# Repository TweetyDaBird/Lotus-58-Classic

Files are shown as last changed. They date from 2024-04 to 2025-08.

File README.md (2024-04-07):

### Notice! Files in the development branches are NOT intended for public use in production of PCB's, may or may not be tested and may change or be removed without notice! 
Please use the Gerber files for producing PCB's, found under the header 'Releases' instead. Also please note the difference between a 'Pre-release' (partially/fully untested, basically what I order a prototype PCB from to test) and a full actual 'Release' which is fully tested, built and ready to be used to produce PCB's.

That said, if you want to tweak/change or make something new based on my project, I can point you to a suitable starting point in the raw files. Talk to me, and I'm happy to help.
# Lotus 58 Glow

Starting with simple tweaks to the Lily58 Glow before ordering a set of PCB's it quickly spiraled out of control, and I ended up with what wasn't quite a Lily58 anymore, and although very similar in layout, it is no longer compatible with plate and case design. 

Because of this, it was renamed Lotus58, referencing another flower much like the lily in the name Lily58.

Lotus 58 Glow
(photo from reddit by u/bduzik)

## General Specifications

- Layout very similar to the original Lily58 family
- Per key RGB and RGB underglow
- Kaihl Hot-swap sockets for MX compatible switches
- Can be used as a standalone Gamepad for either hand
- Optional 0.91" OLED Screens and rotary encoders (one each per side)
- All components through-hole and easily soldered for beginners (SMD option for diodes)
- Designed with a sandwich-style plate/case as part of the design

## Layout variations

- Optional plate layout with OLED screen (Encoder can be placed on upper thumb key position)
- Optional plate layout with rotary encoder (Removes OLED screen for that side)  
- Optional plate layout with no hole for OLED or upper encoder (Encoder can be placed on upper thumb key position)

Layout variations Layout Variations

## Things to note when ordering PCB's
### Finding the Gerber files
If you are not aiming at modifying things, don't look for the gerber files in the folders, pretty please!</BR>
And please don't open yet another issue about it! </BR>
The gerber files are where they belong, zipped up in releases, look under that header for the version you want.

### Tips & Tricks
- Most PCB manufacturers have a MOQ of 5 PCB's, meaning you end up with 2½ keyboards when finished.
- The recommended PCB thickness is 1.6 mm, both for the main PCB and plates to allow the keyswitches to grip the plate and lock in place securely.

If ordering from [JLCPCB](https://www.jlcpcb.com) the plate Gerber files include a reference putting the added serial etc on a breakaway part for a clean look with minimal cost, if using another manufacturer it's possible they have additional fee's for removing the extra text, or you should consider plotting the Gerber files yourself with the correct reference for your manufacturer. Otherwise use the standard settings from JLPCB.

## Buy a kit!
I sell complete kits, making it easy to build your keyboard, and it also supports prototypes for new wacky ones. 



## Discord for build help and discussions!

<a href="https://discord.gg/G6QzcJQUnm">Discuss on Discord</a>

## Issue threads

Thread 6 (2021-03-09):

Latest version

fi0, 2021-03-09:
Which version should I build?

azzamsa, 2021-03-10:
Yes, According to the timestamp `5 days ago`. `v1.06` is the latest release.

TweetyDaBird, 2021-03-12:
The plates and PCB's are in separate packages, since you cannot order them as one item from a manufacturer (one order, but multiple items). As such, they have separate version numbers.

So for a complete keyboard you'd need the v1.1 PCB's and bottom plates plus whichever top plates you pick to go along with them, from either package of plates.

fi0, 2021-03-12:
Thank you! I was confused with PCB versions and plate versions. I should have looked into https://github.com/TweetyDaBird/Lotus58/releases instead of the tags.

Closed 2021-03-12.

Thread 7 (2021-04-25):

Lily58 plates

fabioluciano, 2021-04-25:
Can I use my lily58 pro plates with lotus? Or there is some differences that make this impossible?

TweetyDaBird, 2021-05-17:
No, you cannot, as the outline and hole pattern aren't the same

Closed 2021-05-17.

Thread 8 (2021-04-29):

Resistor

fi0, 2021-04-29:
Is the 2W 4.7k resistor the right one?
or can I get smaller ones?

TweetyDaBird, 2021-05-17:
That link has been corrected, 2W will be far to bulky to fit properly.

Closed 2021-05-17.

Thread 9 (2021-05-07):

Reset switch BOM

fi0, 2021-05-07:
Which reset switch should I buy?

resoursa, 2021-05-07:
No need switch, just short [2nd and 3rd ](https://cvws.icloud-content.com/B/AVL4BtLX9XralGjamo27pjZ8xJKQAZJxWLW_ZPGzBZRlLMc_Q9SvoXsU/Screenshot+2021-05-07+at+09.17.07.png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)contact on arduino.

Closed 2021-05-19.

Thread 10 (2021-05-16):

LED pinouts not the same for SK6812MINI and SK6812MINI-E

mwmccarthy, 2021-05-16:
The pinout for the SK6812-MINI matches the orientation of the PCB for soldering from the bottom with the lens facing away from you as you solder:

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

However, the SK6812MINI-E would need to be soldered from the top of the PCB with the lens facing up in order for the VDD and GND pins to line up, but then DIN and DOUT are swapped:

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

TweetyDaBird, 2021-05-17:
Well, that's altogether stupid that I hadn't verified that part. I have only built with wigless, and figured (without checking) that tehy had the same pinout.

Removing them from parts list.

phil123456, 2024-05-06:
there are so many pinouts of the mini version, which one is correct ? does this depend of the manufacturer or are they all the same ?

TweetyDaBird, 2024-05-06:
> there are so many pinouts of the mini version, which one is correct ? does this depend of the manufacturer or are they all the same ?

Each standardized model has a pin out. That's the same from whatever seller, as they all come form the same producer. But no, mini and mini-e are not the same, and never will be.

Closed 2021-05-17.

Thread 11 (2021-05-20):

Pro Micro RP2040

dunkfordyce, 2021-05-20:
https://www.sparkfun.com/products/17717

Apart from the code changes, would this theoretically work as a drop in replacement?
They are half the price of a standard Pro Micro. I have already had luck using CircuitPython on a plain RPi Pico to create a mech keyboard.

TweetyDaBird, 2021-05-20:
Well, since it’s pin compatible with ProMicro I see no reason why not.

dunkfordyce, 2021-05-22:
Thanks!

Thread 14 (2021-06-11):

Incorrect TH diode identifier

AbhilashGayen, 2021-06-11:
In readme, for diodes,
- update 1N4841(TH) to 1N4148(TH)

TweetyDaBird, 2021-06-16:
Fixed, thank you!

Closed 2021-06-16.

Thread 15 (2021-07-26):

Symmetrical design in Gerbers?

ruehri, 2021-07-26:
Sorry if this is a stupid question (this is the first keyboard that I plan to build): Are all the Gerber files (especially the PCB) symmetrical in a sense that we can use them for both right and left hand? So if I made an order from JLCPBC for 5x the PCB, I could build 2.5 full keyboards - no need for any mirroring of the design, correct?

TweetyDaBird, 2021-07-27:
Exactly correct, the PCB's are symmetrical. You will however 'need' the plates as well to make a complete keyboard. Either as PCB material, or laser cut etc.

ruehri, 2021-08-12:
Thanks! Ordered them (along with all the other stuff from Ali) and look forward to building it

Closed 2021-08-12.

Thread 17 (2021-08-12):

Where is the breakaway part for when you order from JLCPCB?

SuperNici, 2021-08-12:
You mentioned [here](https://github.com/TweetyDaBird/Lotus58#things-to-note-when-ordering-pcbs) that you have added a breakaway part on the PCB Gerber files.

> If ordering from JLPCB the plate Gerber files include a reference putting the added serial etc. on a breakaway part for a clean look with minimal cost, if using another manufacturer it's possible they have additional fee's for removing the extra text, or you should consider plotting the Gerber files yourself with the correct reference for your manufacturer.

I've been looking for it for a while and couldn't find it.

Hybrid-Force, 2021-08-16:
Hey there, I think the breakaway parts were removed in commit 5263f9b0050a36a8181bea90f3474fcbf5af5144. The reference text for serial number was originally on the breakaway part of the upper thumb key.

TweetyDaBird, 2021-08-23:
This depends on if you pick the plates with breakaway parts in the switch holes or not. The plates are available both ways to allow it to work with all PCB manufacturers.

Usually the text is small an unobtrusive enough that it’s hidden under the keycaps, but if you choose to order the PCB’s yourself, it’s worth to check and re-render as needed. Or pay the usually minimal fee to have the text removed. My comment was more aimed at making you aware of this, than an exact roadmap to how to order.

BTW, if you prefer to not bother with ordering yourself, I’m selling PCB kits on tindie at what I think are pretty reasonable prices.

SuperNici, 2021-08-23:
Appreciate the comments @Hybrid-Force and @TweetyDaBird.

I feel like playing the small extra fee on jlcpcb will be worth it.

>BTW, if you prefer to not bother with ordering yourself, I’m selling PCB kits on tindie at what I think are pretty reasonable prices.

You should absolutely put that in the read me! I would have never known! Though for myself i will (soon) order the parts myself because I'll be adding some small stuff to the pcb.

And to support these kinds of open source projects ill also make sure to donate a small amount to you three main contributors :)

Closed 2021-08-23.

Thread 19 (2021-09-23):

Various question

dmikhalsky, 2021-09-23:
Hi,

I am considering to order PCBs so couple of questions:
- what is the latest and the most correct layout? The one in the "Releases" section?
- am I correct that LEDs are "legless, SMD-type"? If so, how do they soldered if they are flush with PCB surface? In this case, solder **joint** is the only connection
- the height of the LED is 1.1mm. Provided the PCB thickness is 1.6mm, LED will reccessed 0.5mm lower than PCB surface. Is this OK?

TweetyDaBird, 2021-09-26:
- Yes, the releases is where you should look for production ready files.
- The RGB's are indeed without 'legs' or 'tabs' (have a look at the linked items on the front page), and while they are 'flush' the hole is narrow enough that they will catch on the edges of the RGB body and sit inside the hole. Dragging the solder tip across to bridge the pads, solders it in place quite firmly.
- It's usually a little less in reality, but yes, this is correct and perfectly OK.

Side note, the 'winged' RGB's are a different pinout and do NOT work.

Closed 2021-09-27.

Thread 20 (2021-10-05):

RGB leds power draw problem

mattscooter, 2021-10-05:
Firstly thank you for your work on this.  You've made everything so easy to order with links to the Aliexpress.  I really appreciate it!

I recently finished soldering everything and have run into an issue with the RGB leds.  Note that I have wired up the 58 individual keys but not the underglow leds.

To get the firmware built I took the lotus58 folder from the keyboard folder in your qmk_firmware fork and put it into my local qmk environment (running v14.19).

With the RGBs disabled the keybord is working fine.  With the default in your config of 6 leds on each hand everything is working fine.

The issues started when I enabled all RGB leds on both sides. I managed to get everything lit up and could briefly change colours but then after a short while the half that's plugged in would keep working for a while and the other half would stop.  Then after a little while longer the keyboard stopped responding altogether.

If I enabled only 34 leds - everything is stable.  When I enable more than this the system started acting up as above.  It doesn't matter how many leds are enabled on each hand I could have all of one hand lit and only a few on the other such as RGBLED_SPLIT { 29, 5 } or an even number on each hand.

After much testing I have identified that I can enable all of the leds but it's the brightness that's causing the issue.  If I restrict the brightness to a maximum of 125 I can get all LEDs lit on both hands.  Does this mean that the system is failing because it's trying to draw too much power to light all of the leds at full brightness?

So I have a work around in setting the max brightness to get everything working but I was wondering if it's possible this is an issue with my RGB led circuit that could be causing the problem?  Have you run into this problem before? If not do you have any tips for how I might be able to debug it?

TweetyDaBird, 2021-10-05:
Hi Matt,

That’s not even a bug/problem, that’s just simple math!

The RGB LEDs use between 4 mAh and 50 mAh each depending on brightness. 58 of them at full brightness is 2900 mAh and the USB port can only supply 500 mAh.

The design was never meant to support all 58 RGB’s at full brightness, as that would be outright blinding. Also, the RGB’s was chosen for the ability to have great colors and light at less than full brightness and work with the power limits.

Using the under-glow though, you can ramp up the brightness fairly high, and it’s more useful that way, as the light is indirect. That’s why I didn’t include the brightness limit as it was configured.

What happens is fairly simple really. As the brightness ramp up on the RGB’s on the USB supplied hand, the voltage drops over the TRRS and the slave side stops working as it plain and simple crashes.

Setting the brightness limit to ~100 isn’t really a workaround, but the correct and intended way to do it. 125 ish would work as long as you don’t set the color to white, or use the type of effects that changes the color too fast.

So sorry, but your keyboard is working perfectly, no debugging needed!

/Markus

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

mattscooter, 2021-10-07:
Thanks for the explanation!  I suspected that this was what was happening after I did all of my testing.

I'm glad to hear that my keyboard is working as expected.  Now I just have to design and print a 3d case for it and I can finish the build off!

By the way I'm starting to try and configure the RGB led matrix.  This means defining the g_led_config with the appropriate led indexes and positions.  Have you, or do you know if anyone else has already done this?

TweetyDaBird, 2021-10-07:
There are plenty of people that have configured it, but AFAIK none of them have shared the code (as of yet).
And I admit to being lazy, once I had verified that it all worked, I decided to stick with under-glow for my at-glance layer indications, and didn't really bother with the rest.

mattscooter, 2021-10-09:
Fair enough.

I've had a bit of an attempt and I'm pretty happy with the results so I'm happy to share my code here in case someone else is looking.

```
 led_config_t g_led_config = {
  {
        // left hand switch matrix to led map
        {  5,  4,  3,  2,   1,   0 },
        {  6,  7,  8,  9,  10,  11 },
        {  17, 16, 15, 14,  13, 12 },
        {  18, 19, 20, 21, 22,  23 },
        {  NO_LED, 28, 27, 26, 25, 24 },

        // right hand switch matrix to led map
        {  40, 39, 38, 37,  36,  35 },
        {  41, 42, 43, 44,  45,  46 },
        {  52, 51, 50, 49,  48,  47 },
        {  53, 54, 55, 56,  57,  58 },
        {  NO_LED, 63, 62, 61, 60, 59 }
    },
    {
        // Left Hand switch led positions
        {86,0},   {69,0},   {52,0},   {34,0},   {17,0},   {0,0},
        {0,16},   {17,16},  {34,16},  {52,16},  {69,16},  {86,16},
        {86,32},  {69,32},  {52,32},  {34,32},  {17,32},  {0,32},
        {0,48},   {17,48},  {34,48},  {52,48},  {69,48},  {86,48},
        {103,40}, {103,64}, {78,64},  {60,64},  {43,64},

        // Left Underglow led positions
        {52,64},  {86,48},  {9,48},
        {9,0},    {43,0},   {78,0},

        // Right Hand switch led positions
        {138,0},  {155,0},  {172,0},  {190,0},  {207,0},  {224,0},
        {224,0},  {207,16}, {190,16}, {172,16}, {155,16}, {138,16},
        {138,32}, {155,32}, {172,32}, {190,32}, {207,32}, {224,32},
        {224,48}, {207,48}, {190,48}, {172,48}, {155,48}, {138,48},
        {121,40}, {121,64}, {146,64}, {164,64}, {181,64},

        // Right Underglow led positions
        {172,64}, {129,48}, {215,48},
        {215,0},  {181,0},  {146,0}
    },
    // led flags
    {
        LED_FLAG_KEYLIGHT, LED_FLAG_KEYLIGHT, LED_FLAG_KEYLIGHT, LED_FLAG_KEYLIGHT, LED_FLAG_KEYLIGHT, LED_FLAG_KEYLIGHT,
        LED_FLAG_KEYLIGHT, LED_FLAG_KEYLIGHT, LED_FLAG_KEYLIGHT, LED_FLAG_KEYLIGHT, LED_FLAG_KEYLIGHT, LED_FLAG_KEYLIGHT,
        LED_FLAG_KEYLIGHT, LED_FLAG_KEYLIGHT, LED_FLAG_KEYLIGHT, LED_FLAG_KEYLIGHT, LED_FLAG_KEYLIGHT, LED_FLAG_KEYLIGHT,
        LED_FLAG_KEYLIGHT, LED_FLAG_KEYLIGHT, LED_FLAG_KEYLIGHT, LED_FLAG_KEYLIGHT, LED_FLAG_KEYLIGHT, LED_FLAG_KEYLIGHT,
        LED_FLAG_KEYLIGHT, LED_FLAG_KEYLIGHT, LED_FLAG_KEYLIGHT, LED_FLAG_KEYLIGHT, LED_FLAG_KEYLIGHT,

        LED_FLAG_UNDERGLOW, LED_FLAG_UNDERGLOW, LED_FLAG_UNDERGLOW,
        LED_FLAG_UNDERGLOW, LED_FLAG_UNDERGLOW, LED_FLAG_UNDERGLOW,

        LED_FLAG_KEYLIGHT, LED_FLAG_KEYLIGHT, LED_FLAG_KEYLIGHT, LED_FLAG_KEYLIGHT, LED_FLAG_KEYLIGHT, LED_FLAG_KEYLIGHT,
        LED_FLAG_KEYLIGHT, LED_FLAG_KEYLIGHT, LED_FLAG_KEYLIGHT, LED_FLAG_KEYLIGHT, LED_FLAG_KEYLIGHT, LED_FLAG_KEYLIGHT,
        LED_FLAG_KEYLIGHT, LED_FLAG_KEYLIGHT, LED_FLAG_KEYLIGHT, LED_FLAG_KEYLIGHT, LED_FLAG_KEYLIGHT, LED_FLAG_KEYLIGHT,
        LED_FLAG_KEYLIGHT, LED_FLAG_KEYLIGHT, LED_FLAG_KEYLIGHT, LED_FLAG_KEYLIGHT, LED_FLAG_KEYLIGHT, LED_FLAG_KEYLIGHT,
        LED_FLAG_KEYLIGHT, LED_FLAG_KEYLIGHT, LED_FLAG_KEYLIGHT, LED_FLAG_KEYLIGHT, LED_FLAG_KEYLIGHT,

        LED_FLAG_UNDERGLOW, LED_FLAG_UNDERGLOW, LED_FLAG_UNDERGLOW,
        LED_FLAG_UNDERGLOW, LED_FLAG_UNDERGLOW, LED_FLAG_UNDERGLOW
    }
 };

```

But now I think I've gone way off topic and you've answered my initial question so I'm going to close out this issue!

Closed 2021-10-09.

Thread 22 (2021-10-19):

Prerelease - Encoder slots are too close to microcontroller pads

nettema, 2021-10-19:
I have ordered the PCB prototype of Lotus58 v1.2 Glow on allpcb.com. And it appeared that they can't produce it as it is now. Here is the photo of the issue.
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

 Probably, the best solution would be to move those encoder slots closer to the center, which would give some extra space between them and Arduino slots, probably this still would allow to secure encoder in place. Or avoid making those holes at all, and trim those legs from the encoder, which wouldn't affect functionality as well.
Also, here is a request for change from the allpcb.com engineers.

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

TweetyDaBird, 2021-10-21:
Thanks!

That’s all I ask really! Feedback is good even if it’s bad.

nettema, 2021-11-26:
Hi! Received the plates recently and already had a chance to test them with an encoder. I had a pair of different ec11 encoders, and they both could be installed on the PCB without any problems. Even though they had a little difference in how the encoder's housing was made, the footprint matched well, but probably some modification to the top plate with the encoder will be needed because to install it with one of the encoders I've had to file the hole a little on horizontal edges so that my second encoder could fit, but it worked fine for my other encoder. I will upload some photos later and looks like this issue can be closed.
Also, I have a few ideas on how to make this PCB even better, but I will probably open some other issues for that.

nettema, 2021-12-01:
So here is a final look at what I managed to assemble from your v1.2 PCBs ) There were no issues with installing components on PCB, but had to enlarge a little the upper encoder hole for the top plate. Also, I had to bridge with wire the underglow and Perkey RGB, but it was nice to find that in 1.21 version you have added the jumper feature for that ) Waiting to see how your project will evolve in time. It was a great pleasure to assemble it and now just enjoying using it!)
Also, I have made 3d model of a case for lotus and will add it on Thingiverse sometime later, so you could probably add a link to it in wiki later.
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

Closed 2021-12-01.

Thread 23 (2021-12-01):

Support for second encoder on one half

nettema, 2021-12-01:
I tried to implement the second encoder on the same half of the keyboard. Looks like there are even 2 ways to implement that.
1. Since when we use the upper encoder instead of an OLED display, we have 2 additional pins freed. So after trimming the traces that were connecting the lower encoder to the ENCODERS_PAD_A/B, and wiring up the lower encoder's pins to R1, R2 pads I've managed to make it work as a separate encoder on the same half. So probably adding some jumpers and additional wires could do the job well
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

2. QMK allows configuring encoders in such a way that they can share same pin for both of them, hence, only 3 pins are used to make them work. So it's possible to use B5 pin for the lower encoder and define the handedness in another way, for example by EEPROM or by #define instruction. Also, probably, it's possible to define handedness by pin only on half with OLED display.
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

TweetyDaBird, 2021-12-02:
Well, unfortunately assigning the hands have to be done the same on both sides, leaving a pin 'floating' with no high/low on the matrix for the hands on the slave side won't end well. So yeah, it can be done with EE_Prom settings etc. but it has to be uniform.

It won't make it into the revision of the keyboard I'm doing now since I'm already prototyping, and 'just adding the traces' is a bit more involved, but it's definitely going on the list of things considered for the next version.

Closed 2021-12-02.

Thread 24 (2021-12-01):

Support for "Touch Screen"

nettema, 2021-12-01:
It would be nice to add pads to solder the thin tactile button underneath the OLED display. Since the display have some freedom of movement, so when it's placed right above the button when you press the display it can actuate that tactile button which works as a regular keypress and appears like the display have some touchscreen capabilities. Here are some photos of how I have placed the button on the PCB and how I have wired it up. It worked out for me very nicely, and I really like how it appeared, after all. So probably more people would like to make it this way.
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

TweetyDaBird, 2021-12-02:
Unfortunately its not quite as simple as just adding the traces, there needs to be room for them and other important traces as well (and there really aren't much space).

And coupled with the fact that this is a more DIY oriented modification, where you are putting pressure on your OLED and the solders to it, which can potentially break it, I'm going to have to say that this probably wont be made a part of the design.

It's a cool mod though, and with you opting to do it on your own, what you do with your OLED is up to you.

Closed 2021-12-02.

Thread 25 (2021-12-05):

jumper pad questions

nathish, 2021-12-05:
Just received the v1.21 pcbs and have a couple of questions regarding the jumper pads. I'm assuming I need to jump one of the pads to the middle to get the LEDs to work but I'm not sure which.

I have the per key and underglow LEDs soldered already, with the intention of using both. Can you let me know what pads I should jump to get all LEDs to work on both hands?

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
Also, I'm curious as to what these pads are used for. Appreciate that this is a pre-release so I'm asking for the docs that have yet to be published. thanks in advance.
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

TweetyDaBird, 2021-12-06:
Let’s start backwards, it’s that kind of day for me!

1. Reset, easily accessible on both sides for a screwdriver or whatever.

2. Designates left/right hand.

3. If you close ‘per key’ RGB AND this jumper, you create a full string of the RGB for it all to work. Not really recommended for high output/high power draw, but feasible at low intensity.

nathish, 2021-12-06:
Perfect, thanks for the quick response. one more question before I solder the battery switch. below switch S1, the plus and negative pin holes, just want to double check that these route to the power and ground of the MCU (nicenano v2 in my case)?

TweetyDaBird, 2021-12-07:
They route to the switch and then the raw/batt+ pin and GND/batt- so meant for the battery.

Closed 2021-12-07.

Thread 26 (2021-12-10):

Breakaway tabs referenced in readme

mrherman, 2021-12-10:
The ReadMe has a section titles "Things to note when ordering PCB's" but looking at the kicad_pcb files in the Plate directory I don't see any with breakaway tabs.  I do see a jpg in the same directory that shows a pictiue of a rendering of a board with breakaway pads.  Do pcb files of these plates exist (am I just looking in the wrong place)?  Do I need to do something to generate them?

TweetyDaBird, 2021-12-11:
Yes, you are likely just looking in the wrong place.

You can generate the files from KiCad yourself if you like, the data is there if you look for both with and without tabs.

But if you’re not looking to modify things, just go to releases, and you’ll find the gerber files.

mrherman, 2021-12-16:
I didn't see the with tabs in KiCad.  I looked at both branches.

TweetyDaBird, 2021-12-17:
Well, since the plates without tabs were generated last and from the ones with tabs, the saved code in the open development is just as you say without the tabs.

If you however look at the snapshot of code from when the plates with tabs were generated (included as a zipped file in the release) that's the exact data it was generated from, and thus without tabs.

Its also possible to find the exact commit where the same data exist by looking in that history, but since you have a release to go by, that would be the easiest way.

However, I'm genuinely curious what you want the PCB file for that you can't do with the gerber? Manufacturing the plate as a PCB will need the gerber, and editing the PCB will generate a lot of errors in the DRC as it's not a complete PCB with a complete schematic, so less trivial than the actual PCB infact.

mrherman, 2021-12-17:
Thanks Markus.  It didn't dawn on me that a commit would over-write the with tabs with without tabs.  I was expecting two separate files.  I can see them now.

I wanted the PCB files because I am making a small change to the layout.  I am familiar with KiCad that I shouldn't run in to problems.

Thanks for the help.

TweetyDaBird, 2021-12-17:
Well, if it was a full on PCB I would obviously have made it as separate files etc. but for just retaining the outline and such to make a plate or versions of it, I was a little lazy.

Closed 2021-12-11.

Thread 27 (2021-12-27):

Issue with communications

NarenHT, 2021-12-27:
Hi,

I am having issues with the communication between the boards.
I have made the older Lotus58 v1.11. I have only modified your firmware in the keymap.c file and the lotus58.h file to use the default lily58 keymap instead. Everything else is identical to your firmware. I have closed serial and added i2c resistors. I have an oled on the right and an encoder on the left. Keys everywhere else. TRRS cable shows continuity.

My primary issue is that only the board connected to the USB works. I am sometimes able to start the display on the right, when the usb is connected to the left but it will only display the boot image at best.

Both my power jumpers are open. Is this the problem? Should I always connect to the right and close the right power jumper?
Something like this: https://docs.splitkb.com/hc/en-us/articles/360010588860-Only-one-half-of-my-keyboard-works-at-a-time-but-not-when-they-are-both-connected

Your help is appreciated!

NarenHT, 2021-12-27:
Also, I have no perkey / underglow leds.

TweetyDaBird, 2021-12-27:
Ok, let’s start to unravel this, as some things you are saying aren’t making complete sense for me combined together.

The i2c resistors are only needed on the side using the OLED. And if you are closing the serial jumpers, check that you are in-fact using serial in the .h file. Both options should be in there as it’s optional, can’t remember which is commented out as default, but I think serial will be the active. Also make sure you haven’t closed the i2c jumpers as well, then it’s surely out of whack.

The power jumpers (if we are talking about on the ProMicro) should normally not be closed, but random clones may have other uses for that jumper than default, so double and triple check what it does.

One thing I notice is you didn’t mention if the two sides work/identify as their respective sides when used with USB (ie the correct keys, not mirrored). The way my firmware is set up, if you solder the left/right jumpers, they should work as their respective sides, and then you need to double check that you are connecting USB to the side designated as master. (Connecting to the slave works, but not well). To save on cross traffic, I’d set the OLED side as master.

NarenHT, 2021-12-27:
Hey! Thanks for the fast reply.

i2c are only on the OLED Side. I am using Serial by default. I have commented out the #define USE_I2C for the moment.
The right side has OLED and is set to default master. However, detect USB is enabled also.
Two sides work perfectly individually.
Let me check the solder connections once in the morning. I think I have messed something up then.

p.s. Here's a pic for you! Thanks for the project.
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

TweetyDaBird, 2021-12-28:
Thanks for the pic.

Well, so there is nothing unclear. To use the OLED you do not need to solder the jumpers by TRRS. The i2c lines are already connected.

NarenHT, 2021-12-28:
I might have misunderstood something. Can I close both serial as well as i2c jumpers? Because that's what I have done.

TweetyDaBird, 2021-12-28:
No, most definitely not. That’s causing a short circuit and would be the reason for your issues.

Luckily though, all involved pins should survive the experiment if nothing exceptional has happened.

NarenHT, 2022-01-10:
Thanks. Keyboard is fixed. I forgot to update this. Only noticed that the display will not show data after boot image if the non display side is connected to PC. Otherwise all cool. Keys work and that's all that matters to me. Thank you.

TweetyDaBird, 2022-01-10:
That's most likely because the display is only active on the master (should be the one normally connected to USB/with display) in the firmware. You can tweak it to work regardless, or have different functions depending on which side is plugged in etc. but that's beyond what the basic firmware is intended for, and up to you to fiddle with.

NarenHT, 2022-01-10:
Absolutely. Cheers!

Closed 2022-01-10.

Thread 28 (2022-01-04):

Can't find what to short to use serial (v1.21)

wigeric, 2022-01-04:
Hi,
thanks for all your amazing work but I'm unable to find what jumper to short for using serial (2 oled screens).

The wiki says
`If using Serial, close the one single jumper above the TRRS socket on both PCB's Required when using two OLED screens`

But the only things I'm able to see above the TRRS socket are :

- D30 for encoder
- Jumper for hand
- Jumpers for OLED

Could you point me in the right direction ?

TweetyDaBird, 2022-01-04:
Actually, I can’t. That wiki/build guide is for the v1.x versions only. And the reason it’s not yet updated is that you are building from a prerelease.

And while the particular release you used was removed because it has other issues, in its description there was a hint. The PCB no longer has any jumpers for i2c/serial since it no longer supports using i2c for the TRRS. It’s hardwired to serial and the displays are wired up to i2c. No conflicts that way.

wigeric, 2022-01-04:
Thank you, that answers my question.

Closed 2022-01-04.

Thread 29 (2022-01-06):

How to test the keyboard ?

Araly, 2022-01-06:
Hey,

I've been building this keyboard as my first soldering project, and I'm pretty sure I've done several mistakes in it. Two of the breakaway bridges broke (the left-hand indicator on the left board, and the lower i2c bridge on the right board) and I soldered them back, but I'm not sure if this would actually work. I'm trying to understand if I've ruined the boards or if it's salvageable, and how I could test the connections. I'm also trying to understand how to compile / configure / flash the firmware once I'm done soldering the microcontrollers.

I've socketed the first controller, but I find it very hard to remove it from its socket. I'm able to leverage on its back, but I can't find a way to pull it off its front where the USB port is, as I don't want to damage it.

Is there a way I can see what is supposed to connect with what ? I'm thinking of buying a multimeter to see where if the bridges that are broken are still making a connection or not. A friend said to wire things together to bypass the bridge if they are ruined.

I've found this repo https://github.com/TweetyDaBird/qmk_firmware that you seem to mention in another issue being the forked firmware to use for the board, but looking around I couldn't find how you're supposed to compile it or what you need to do to flash it. I also see that the section for it is missing in the wiki. Is there maybe another set of instructions I can follow and adapt to Lotus ?

The issues I had with the bridges were after soldering them together with neighboring things, and trying to disconnect them by cutting the excess of solder between them. It seems like the tip I'm using on my soldering station is too thin and doesn't transmit heat well, making me have to use the side of the tip instead, and being more messy with the soldering. So I'm thinking of buying larger or differently shaped tips instead.

Thanks

Araly, 2022-01-07:
I see, I understood that Serial was to be used for when you had a special case, can't rememeber if it was two OLED screens maybe, so I assumed i2c was the default recommended one. I guess I could remove the solder from the i2c bridges and go Serial instead.

I'll try the scrapping off method to repair the LH left hand bridge indicator.

Thanks for the quick reply ^^

TweetyDaBird, 2022-01-07:
A few versions back, i2c was the preferred option, with lower latency etc. A couple of rewrites of the code later, it really doesn’t matter much, and serial gives more options. Essentially you can pick either or.

Araly, 2022-01-07:
using a multimeter I was able to check what worked and what didn't, scraped off one of the bridges and replaced it with some diode leg instead. Multimeter beeps where I expect it should so that seems fine.

I'm trying to compile the firmware now, I've installed qmk with `yay -S qmk` and I cloned your fork. I copied the `keyboard/tweetydabird` to the qmk's own keyboard folder, and tried to run `qmk compile -kb tweetydabird/lotus58 -km default`, but that failed

```
$ qmk compile -kb tweetydabird/lotus58 -km default
Ψ Compiling keymap with make --jobs=1 tweetydabird/lotus58:default

QMK Firmware 0.15.12
☒ Not including data from file: keyboards/tweetydabird/lotus58/info.json
☒       layouts.LAYOUT: Additional properties are not allowed ('key_count' was unexpected)
Making tweetydabird/lotus58 with keymap default

☒ Not including data from file: keyboards/tweetydabird/lotus58/info.json
☒       layouts.LAYOUT: Additional properties are not allowed ('key_count' was unexpected)
avr-gcc (GCC) 11.2.0
Copyright (C) 2021 Free Software Foundation, Inc.
This is free software; see the source for copying conditions.  There is NO
warranty; not even for MERCHANTABILITY or FITNESS FOR A PARTICULAR PURPOSE.

Compiling: keyboards/tweetydabird/lotus58/keymaps/default/keymap.c                                 In file included from quantum/action.h:23,
                 from quantum/keymap.h:22,
                 from quantum/quantum.h:21,
                 from keyboards/tweetydabird/lotus58/lotus58.h:19,
                 from keyboards/tweetydabird/lotus58/keymaps/default/keymap.c:16:
quantum/keycode.h:100:17: error: redeclaration of enumerator 'KC_NUM_LOCK'
  100 | #define KC_NUM  KC_NUM_LOCK
      |                 ^~~~~~~~~~~
keyboards/tweetydabird/lotus58/keymaps/default/keymap.c:27:5: note: in expansion of macro 'KC_NUM'
   27 |     KC_NUM,
      |     ^~~~~~
quantum/keycode.h:328:5: note: previous definition of 'KC_NUM_LOCK' with type 'enum hid_keyboard_keypad_usage'
  328 |     KC_NUM_LOCK,
      |     ^~~~~~~~~~~
keyboards/tweetydabird/lotus58/keymaps/default/keymap.c:204:6: error: conflicting types for 'oled_task_user'; have 'void(void)'
  204 | void oled_task_user(void) {
      |      ^~~~~~~~~~~~~~
In file included from quantum/quantum.h:180,
                 from keyboards/tweetydabird/lotus58/lotus58.h:19,
                 from keyboards/tweetydabird/lotus58/keymaps/default/keymap.c:16:
drivers/oled/oled_driver.h:290:6: note: previous declaration of 'oled_task_user' with type '_Bool(void)'
  290 | bool oled_task_user(void);
      |      ^~~~~~~~~~~~~~
 [ERRORS]
 |
 |
 |
make[1]: *** [tmk_core/rules.mk:457: .build/obj_tweetydabird_lotus58_default/keyboards/tweetydabird/lotus58/keymaps/default/keymap.o] Error 1
Make finished with errors
make: *** [Makefile:478: tweetydabird/lotus58:default] Error 1
```

compiling the example keyboard seems to work though. I'm following this guide: https://docs.qmk.fm/#/newbs_getting_started

Araly, 2022-01-07:
was able to get it working by using the entire fork instead of just copying the keyboard/tweetydabird/lotus58 directory. I also needed to install qmk with python instead of pacman, as the avr-gcc was too new, and it made the firmware too big

TweetyDaBird, 2022-01-07:
Well, it seems I need to update it to the newest version then.

Araly, 2022-01-07:
I'm currently running into an issue where
```
Device /dev/ttyACM0 has appeared; assuming it is the controller.
Waiting for /dev/ttyACM0 to become writable..........................................................................
```

I see that I don't have the rights to write to the device, is there a thing I'm missing ? It doesn't seem like the device belongs to any groups I can add my user to, and I can't run `qmk flash` with sudo

Araly, 2022-01-07:
needed to run the recommended command in `qmk setup` reguarding udev, was able to flash one side

TweetyDaBird, 2022-01-07:
Unless you have wondered both sets of jumpers, I’d assume your problem is firmware, since it is set up for serial, so yes you’d need to change most of that.

Correct on switching master.

Araly, 2022-01-08:
I soldered both I2C jumpers on both sides, and I haven't soldered the serial jumpers. Where do the I2C jumpers connect ? I'd like to be able to test that they do connect properly.

What should I change ? I tried commenting out the serial line and replacing it with USE_I2C, but when I flash that nothing works anymore, not even the sides individually. Do I need to also remove the other serial lines, or replace them with I2C related lines ?
```c
// #define USE_SERIAL
#define USE_I2C
```

TweetyDaBird, 2022-01-08:
They rather obviously connect between the TRRS and the ProMicro.

Have a look at QMKs docs. It’s outlined step by step making the settings for i2c or serial.

The resistors are not exclusively for the OLED, but needed for i2c period.

Good policy to things step by step.

Araly, 2022-01-08:
if the resistors are needed for i2c, and are not exlusively for the OLED, should I have them on both boards ? I only have them on the left board, where I want to put the OLED

TweetyDaBird, 2022-01-08:
Even if you already fixed it, for completeness, no they are only needed once per i2c system.

Araly, 2022-01-09:
just like mentioned in this diagram yeah https://docs.qmk.fm/#/feature_split_keyboar

I have one more question. I bought an encoder that I want to place on the high corner, above where the controller is. It has metal legs that are said to be snipped off, but it also has bumps like the switches on the bottom. Unlike the switches though, there's no hole for those bumps to go in. Should I also snip off these bumps ?

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
d
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

Araly, 2022-01-09:
I've cut them off, everything seems good so far

TweetyDaBird, 2022-01-12:
Those are new, I haven't seen them on any encoders before.

Araly, 2022-01-14:
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

keyboard looks good and works well, now onto making a comfortable keymap ^^

Closed 2022-01-14.

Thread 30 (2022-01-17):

JLCPCB additional charge to the top plate

npielawski, 2022-01-17:
Hello,

First, thank you for making such a nice split keyboard available :)

I asked JLCPCB to produce the pcb, bottom and top parts, and received an email this morning stating I had to pay extra due to: `Reason: 1.There are too many small slots in your file , it will take too much time to get it finished during the routing process.` in the `Lotus58_Glow_Top_Plate_OLED_Y7` file.

Is there any way we can avoid this charge? The extra charge is about 15.2$. Is this something you had to pay too @TweetyDaBird ?

npielawski, 2022-01-27:
Alright thanks!

Closed 2022-01-27.

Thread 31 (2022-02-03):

corrupt plate dxf files?

sungo, 2022-02-03:
I'm looking to laser cut some plates (new glowforge gotta forge) but it looks like the plate DXF files are corrupt. Peaking inside, it appears the DXFs have gotten wrapped in github html/js fun somehow. Any chance of getting clean DXFs?

TweetyDaBird, 2022-02-03:
Sorry, but those files were never made or maintained by me but by another user. I have no way of recreating them.

sungo, 2022-02-03:
Alrighty. I'll see what I can come up with. If I figure something out, do you want a PR?

TweetyDaBird, 2022-02-03:
Gladly!
While personally I'm quite happy with the FR4 plates, it seems a lot others want to use different materials, hence why they were uploaded here. So I'm happy to take whatever files you come up with.

sungo, 2022-02-07:
Looking through git history, it looks like the corrupt versions were added here. https://github.com/TweetyDaBird/Lotus58/commit/1c34fa41cd076e58e1640e762ec52977901df85a. They appear to be a "save source" of github's HTML view of the original DXF files. I extracted the original files from git history and they import into my tools fine. Haven't tried cutting them yet.

If your intention was to bring those dxf files forward with no changes, I can drop a PR with the original files. Which branch would you like them to land in?

TweetyDaBird, 2022-02-09:
Probably 1.11 branch. Yep, the intent is to keep files intact.

Closed 2022-02-19.

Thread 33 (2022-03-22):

Change in marking for the side and Oled jumpers

slowmotionghost, 2022-03-22:
Hi,
I just received a PCB and am stuck at the first step in the build guide. There looks to be a change in the board compared to the photos on Tindie so I am assuming this is a new version. The topside marking which previously read RH now reads left hand and the OLED jumpers say left hand above them as well (with the board oriented in the right hand position). Am I right in thinking I now join these on the bottom side/component side of the board as opposed to the top side in the build guide?
Thanks

TweetyDaBird, 2022-03-24:
I'll just refer you to the statement on the first page of the build guide. The guide refers to version 1.11 ONLY. Any other susequent versions are obviously different, and when the directions on the PCB are different, please follow the ones on the PCB.

https://github.com/TweetyDaBird/Lotus58/wiki

Closed 2022-03-24.

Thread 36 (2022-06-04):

Compile errors for the Lotus

DorjeDorf, 2022-06-04:
Hi,

If I read correctly, the QMK was changed a while back and it seems your code for the Lotus58 might be incompatible with the new build.

Is there any chance you could review the code and possibly update it or help guide me to where I can fix the problems I am seeing?

This is the output during the compilation. it doesn't matter if I do it in your fork or just files copied to the direct git pull.
I had to reenable debug and print to see these.

Thanks ;)

```
Compiling: keyboards/lotus58/keymaps/default/keymap.c                                              In file included from quantum/action.h:24,
                 from quantum/keymap.h:22,
                 from quantum/quantum.h:21,
                 from keyboards/lotus58/lotus58.h:19,
                 from keyboards/lotus58/keymaps/default/keymap.c:16:
quantum/keycode.h:93:17: error: redeclaration of enumerator 'KC_NUM_LOCK'
 #define KC_NUM  KC_NUM_LOCK
                 ^~~~~~~~~~~
keyboards/lotus58/keymaps/default/keymap.c:27:5: note: in expansion of macro 'KC_NUM'
     KC_NUM,
     ^~~~~~
quantum/keycode.h:321:5: note: previous definition of 'KC_NUM_LOCK' was here
     KC_NUM_LOCK,
     ^~~~~~~~~~~
keyboards/lotus58/keymaps/default/keymap.c:166:6: error: conflicting types for 'oled_task_user'
 void oled_task_user(void) {
      ^~~~~~~~~~~~~~
In file included from quantum/quantum.h:184,
                 from keyboards/lotus58/lotus58.h:19,
                 from keyboards/lotus58/keymaps/default/keymap.c:16:
drivers/oled/oled_driver.h:290:6: note: previous declaration of 'oled_task_user' was here
 bool oled_task_user(void);
      ^~~~~~~~~~~~~~
 [ERRORS]
 |
 |
 |
make[1]: *** [.build/obj_lotus58_default/keyboards/lotus58/keymaps/default/keymap.o] Error 1
make: *** [lotus58:default] Error 1
Make finished with errors
```

TweetyDaBird, 2022-06-10:
Unfortunately, it seem QMK are going through a series of 'breaking changes', so yes the code will need updating. However, it should absolutely work with the fork as is. And I'm unsure how long I can keep updating things, as the QMK main parts keep getting bloated to the point where its soon running out of memory for splits using a Pro Micro.

Will have a look and update, but unfortunately, as life is right now, it wont be immediate, sorry.

DorjeDorf, 2022-06-10:
Fully understood and thank you :)
I know the issue is visible on a Mac (even with a direct copy of your whole github repo).

I tried to compile the code on a very old QMK branch on Windows (just copying the config) - compilation worked, but bricked the arduino (had to reflash the bootloader).

I'll also chip away and will try to figure this out.

RagingCactus, 2022-06-14:
I'm currently building a Lotus58. I have a basic firmware running now, but also very liberally changed the existing code.

I might release it when it's cleaned up a bit, but your specific problem is that `void oled_task_user(void)` was changed to `bool oled_task_user(void)`.

Change it to this:
```c
bool oled_task_user(void) {
    if (is_keyboard_master()) {
        print_status_narrow();
    } else {
        render_logo();
    }

    return false;
}
```

Caveat: I don't really know what I'm doing in QMK, I'm just learning as I go

hundredfire, 2022-06-26:
I managed to compile a working firmware with the latest build of QMK (0.17.0) by modifying some parts that showed errors while compiling:
- removing the 'keycount' line in info.json
- removing the define NO_DEBUG, define NO_PRINT, define NO ACTION_MACRO and define NO_ACTION_FUNCTION in config.h (or just putting them in comments)
- renaming all mentions of layer _NUM to _RAISE and changing custom keycode KC_NUM to KC_RAISE in default/keymap.c (conflict with a new keycode called KC_NUM described in quantum/keymap.h
- At this point, if you try to compile, you will end up with a .hex that is slightly oversized, so I added 'LTO_ENABLE = yes' to my rules.mk

It even somehow managed to make my rotary encoder work, while it wouldn't with the default build provided in this repo.. weird?
I started to meddle with QMK since just a few days ago, so I have no idea what these changes imply, but now it compiles without error. I'm not even sure how to request a pull from my local repo, so I won't be of much help. I would be glad if it could help just a little bit though
Anyways, here is a zip :

[lotus58.zip](https://github.com/TweetyDaBird/Lotus58/files/8987689/lotus58.zip)

RagingCactus, 2022-07-10:
@hundredfire @DorjeDorf

See https://github.com/RagingCactus/qmk_firmware/tree/ragingcactus-develop/keyboards/lotus58 for my firmware.
It contains variants for both the Pro Micro and RP2040 microcontroller boards.

Because of that, it is based on QMK upstream `develop` branch. Feel free to use what you can!

TweetyDaBird, 2022-09-12:
My code was updated a fair while ago if you want to use that

RagingCactus, 2022-09-12:
@zdpkoszur I fixed this in my fork: https://github.com/RagingCactus/qmk_firmware/commit/4999b32b5a03b7e1e680d352d90f086fee1a6232
```
    Lotus58: Specify promicro variant as default

    This prevents build errors when not specifying a variant, for example
    when using the following command:

    qmk compile -kb lotus58 -km ragingcactus

    This will now build the promicro variant by default.

    Use one of the following commands to specifically build a variant:

    qmk compile -kb lotus58/promicro -km ragingcactus
    qmk compile -kb lotus58/kb2040 -km ragingcactus
```

That being said: If you have questions/issues regarding my fork, please direct them to me in the fork repo. I'm just sharing my personal firmware, it is very much "unofficial". I don't want to cause notification spam for the original author because of issues out of their control.

DorjeDorf, 2022-09-13:
Thanks guys ;)

Closed 2022-09-13.

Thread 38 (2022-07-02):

Specify Microcontroller orientation

SuperNici, 2022-07-02:
[Here in the wiki](https://github.com/TweetyDaBird/Lotus58/wiki/3.-Building-the-basic-keyboard-circuit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) it is unclear whether the controller should be mounted facing up, or down.

Pictures would also help a lot.

TweetyDaBird, 2022-07-02:
Easily addressed.

SuperNici, 2022-07-02:
> Place the controller facing the main PCB, on the the backside/component side of each PCB, if socketed flush with the socket, if not socketed place it level as the USB port touches the main PCB.

My bad, its been a long day of troubleshooting ( ; U ;)b

TweetyDaBird, 2022-07-02:
I just edited to add that, so no error on your part.

SuperNici, 2022-07-03:
Ah, Id also like to add that the orientation is only written on the v1.23 version of the PCB:
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

I have the 1.11 one here which doesnt mention it:
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

Closed 2022-07-02.

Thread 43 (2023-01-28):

Bottom plate with tenting support

sdrauksas, 2023-01-28:
Hi Tweety!
I am very thankful to you for putting this all together!

I am currently in the process of putting the keyboard together and I saw that on your store you sell an FR4 bottom plate with additional holes for tenting support, however I was not able to find the files for that in here.

I dug a little bit deeper and saw that the file `FR4_Bottom_Plate_TENT.kicad_pcb` was removed in the commit [70c5d289c95a80e03fcd2d824fd882cb38c4dc72](https://github.com/TweetyDaBird/Lotus58/commit/70c5d289c95a80e03fcd2d824fd882cb38c4dc72) as part of the v1.21 release. Was this on purpose or an accident?

TweetyDaBird, 2023-02-09:
Purely accidental. Should be in there as well.

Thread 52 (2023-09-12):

Short between vcc and gcc

Koshu, 2023-09-12:
Hi,

I am currently building your board and found a short in my PCBs between GND and VCC and in the release gerber files version 1.33.

Looks to me as if the GND plane has not been updated after moving a trace.

Gerber viewer:
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

In PCB:
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

Guess I will now figure out how precise my pcb scratching abilities are 😅. Otherwise nice board btw, first buttons are already working.

TweetyDaBird, 2023-09-12:
Crap. My apologies.

The file will be regenerated/upgraded asap.

Koshu, 2023-09-12:
Don't worry about it, I was able to fix it. Just the usual stuff in DIY projects ;).

Did a few changes because I decided to use a sparkfun rp2040 for some reason but the left hand seems to be working now.

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

TweetyDaBird, 2023-09-13:
Well, it still shouldn't happen. File is now updated.

Closed 2023-09-13.

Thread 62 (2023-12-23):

Version 1.30, 1.31 contain incorrect readme files?

Catacomba, 2023-12-23:
I ordered the 1.33 (at the time latest) version PCB, and when searching for the parts list, because the 1.33 version of the readme does not contain the parts list in the readme, i backtracked the versions. Most recent version to contain the parts list is 1.31. Which i followed when buying parts.

However the readme in folder 1.31 is actually has v1.23 specified in the title (I overlooked this... and used the readme just for the parts list). The same readme also appears to be in 1.30.

These readmes are actually for the TRRS version of the Lotus... and i ordered the USB-C PCBs... I know this is my mistake, because I did not pay attention to the release notes and didn't realize this changed with v1.3.

However I believe that the readmes in 1.30 and 1.31 should be fixed with the correct parts lists or perhaps the TRRS row removed from the parts list or maybe just a simple strike trough, so that it doesn't mislead other people.

TweetyDaBird, 2023-12-23:
Well, unfortunately you overlooked even more than that. Neither v1.30/1.31 or 1.33 reached a full release until 1.33 was moved to that status about three-four weeks ago.  Until then all three were pre-releases (and some still are). And that label signifies just that. Not polished, not fully documented, not ready for public consumption _unless_ the user takes care and either asks questions where applicable, or knows to double check and question info.

And never ever will I take any responsibility for older documentation not matching another version. That's just not the correct way to interpret it.

Advice for the future. Asking questions is a lot better than assuming the answer.

In fact unless you ordered the PCBs in that timeframe, the PCBs may not even have been build tested? (A pre release becomes a full release once build tested). I'm not sure on the timeline here.

And since the releases have been improved (with all but the latest) with tiny little changes that doesn't change the function much, but makes it easier to build or fit a case etc. they will never be full releases, as that will be v1.40 which is intended to be stable for a while.

And as such, it's in the process of getting updated and completed documentation. That always will happen _after_ the build test, and after it reaches a full release. The tags actually matter.

Catacomba, 2023-12-24:
Yeah, I understand i made multiple mistakes.

Regarding my order timeframe. I believe he 1.33 version was already in the latest status (it had a green tag). Which is why I just mindlessly ordered PCBs of this version.

I have a few more questions, but think those belong in the discussions tab or on discord.

I will now close this issue since, due to your explanation, i am unsure that the files in mention should really need editing.

Thank you for providing such a fast and thorough explanation of the release cycle!

TweetyDaBird, 2023-12-24:
No problem!

FYI the 1.33 moved to 'latest release' at the same date as v1.40 was made as pre-release.

Closed 2023-12-24.

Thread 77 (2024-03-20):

JLCPCB questions about PCB order (v1.28)

U-Zd, 2024-03-20:
Hi,
Firstly, thanks for all your work!
I placed an order with the v1.28 gerber files and received the following email from JLCPCB engineer:

"Sorry to bother you, but there is an issue that we want to confirm with you before proceeding.
As shown below, the NPTH were connected with PTH, they will become PTH, we suggest to move those NPTH to ko layer to mill out?"

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

I am sorry, I do not know much about PCB designing so am unable to fix the issue myself
Thanks

TweetyDaBird, 2024-03-20:
Hi there.

Thanks for the praise.

As for the question from JLCPCB it's just them being dumb in the extreme, and suggesting the working way to 'fix' something that isn't an issue.

Answer them this: "No, the PTH holes should not be moved/changed in any way. It's perfectly ok for the NPTH holes to become partially plated, and this should be manufactured as is specified and tested."

And for future reference if anyone is looking for the answer here this applies to all of their silly questions. The design is tested and already manufactured **as specified** by the time it makes it to a release.

TweetyDaBird, 2024-03-20:
Btw. I took the liberty of changing the headline to make it more universal for people searching for answers.

Closed 2024-03-20.

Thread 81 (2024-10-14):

v1.29 TRRS issues: one key stuck & no R1/R2

ClemensSchartmueller, 2024-10-14:
Hi,

I have recently acquired two v1.29 TRRS boards from your shop with two OLEDs and through-the-hole soldering. So far, everything seems to work nicely, except:

1. one side has a key stuck (LH, bottom 3-key row, first key left-to-right) : It seems to me that I somehow shorted the hotswap socket (checked with multimeter and no switch inserted). Is there any fix to that beyond buying a new socket and resoldering it (sadly the order only had the exact amount of parts in it, not a single spare one for beginners like :D) ?
2. The manual says "solder R1, R2 for OLED"  and C1/C2 for an encoder. are the capacitors really needed for encoders? I tested without and it seems to work fine. Also: R1, R2 are not listed on the board - are these the same slots as C1/C2?

Thanks so much in advance for your help!

TweetyDaBird, 2024-10-14:
Hi. Sorry but the kit even though for beginners is based on the assumption that it's really, really hard to mess up the components as such.

I'm willing to be that the socket in itself is perfectly fine, and if you look carefully you have some left over tin somewhere causing the short on the pads/traces. To actually damage/short the socket as such, you'd have to drench it in solder and get it in places quite far from the solder pads. Not impossible but quite unlikely. (If you truly managed to short the socket and can't get the tin out, drop a note in the store, and I'll happily send you a socket, no charge).

Yeah. But the manual also say something at the very beginning that you obviously missed. It states that for every new version refer to the silkscreen as that is always more correct/updated than the manual. And since quite a few revisions back, there are no resistors as they are no longer needed.

Capacitors aren't 'needed' for normal use and to make the encoders 'work'. They are there to prevent noise from the encoder to trigger false key inputs, or make inputs be missed, or even as a worst case reset the controller and restart the keyboard. You can certainly leave them out if you want too, but I'd say it's a small effort to put them in place not to have issues at random.

ClemensSchartmueller, 2024-10-14:
Thanks for the reply. I'll check again! I also removed any potential excess solder with a solder sucker but the problem persists. Do you have a hint what other points could be shorted to show such behavior? I checked the arduino pro micro too.

@R1/R2 and capacitors: thanks, that clarifies things!

TweetyDaBird, 2024-11-08:
Not sure where this ended up. (I have a hard time keeping names across platforms straight.)?

TweetyDaBird, 2025-04-01:
Closed ast there AFAIK are no design issues, and build/user questions belong in discord.

Closed 2025-04-01.

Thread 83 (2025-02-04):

PDF with schematics for each release

chatelao, 2025-02-04:
I ♥️♥️♥️ my keyboard, especially for tinkering. It was my wheelchair to the first steps with KiCAD, learning to delete, move and autoroute a slim Corne42 derivative from it.

If you would add only the schematics to each version, it would be a great service for debugging and patching without KiCAD in the long term. - Just as a maintaince manual.

Not yet there, but working on a automated generation of the documentation on each tag for my projects. But the learning curve is SO steap.

TweetyDaBird, 2025-02-04:
I'll happily put it on the to-do list, but it's going to be low priority, so don't expect it anytime soon.

chatelao, 2025-02-04:
That's totally fine. It was just something I found out today and maybe adding it to new boards will be easy.

** Don't ask how I version my files 😂, sometimes JLC is my last hope.

Closed 2025-04-02.

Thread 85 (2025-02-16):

Micro controller on the right half gets very hot quickly

tim-kilian, 2025-02-16:
Hej,

I've finished assembling the board and everything works ok, but the micro controller on the right side gets very hot. I tried already changing it, but both had the same issue. I have build the left half with Nice Nanos, a rotary encoder, a display and a battery and set it up with basic ZMK firmware with the left being the main board. Do you know what the issue could be? I build the v1.26 version.

TweetyDaBird, 2025-02-16:
Usually if things get hot and do not work, it's a short circuit. But since you are saying it does work that's not the case here.

If I'd hazard a guess, is the OLED on the right side? And could it be the 3.3v regulator that is getting hot? The OLED screen does draw a bit more power than the n!n is really designed for, especially when powered of 3.3v as it's originally intended for 5v, so it would in-fact get at least lukewarm from that throughput.

Other than that, I really have no good guesses.

TweetyDaBird, 2025-04-01:
Closed as there is no design error AFAIK.

Closed 2025-04-01.

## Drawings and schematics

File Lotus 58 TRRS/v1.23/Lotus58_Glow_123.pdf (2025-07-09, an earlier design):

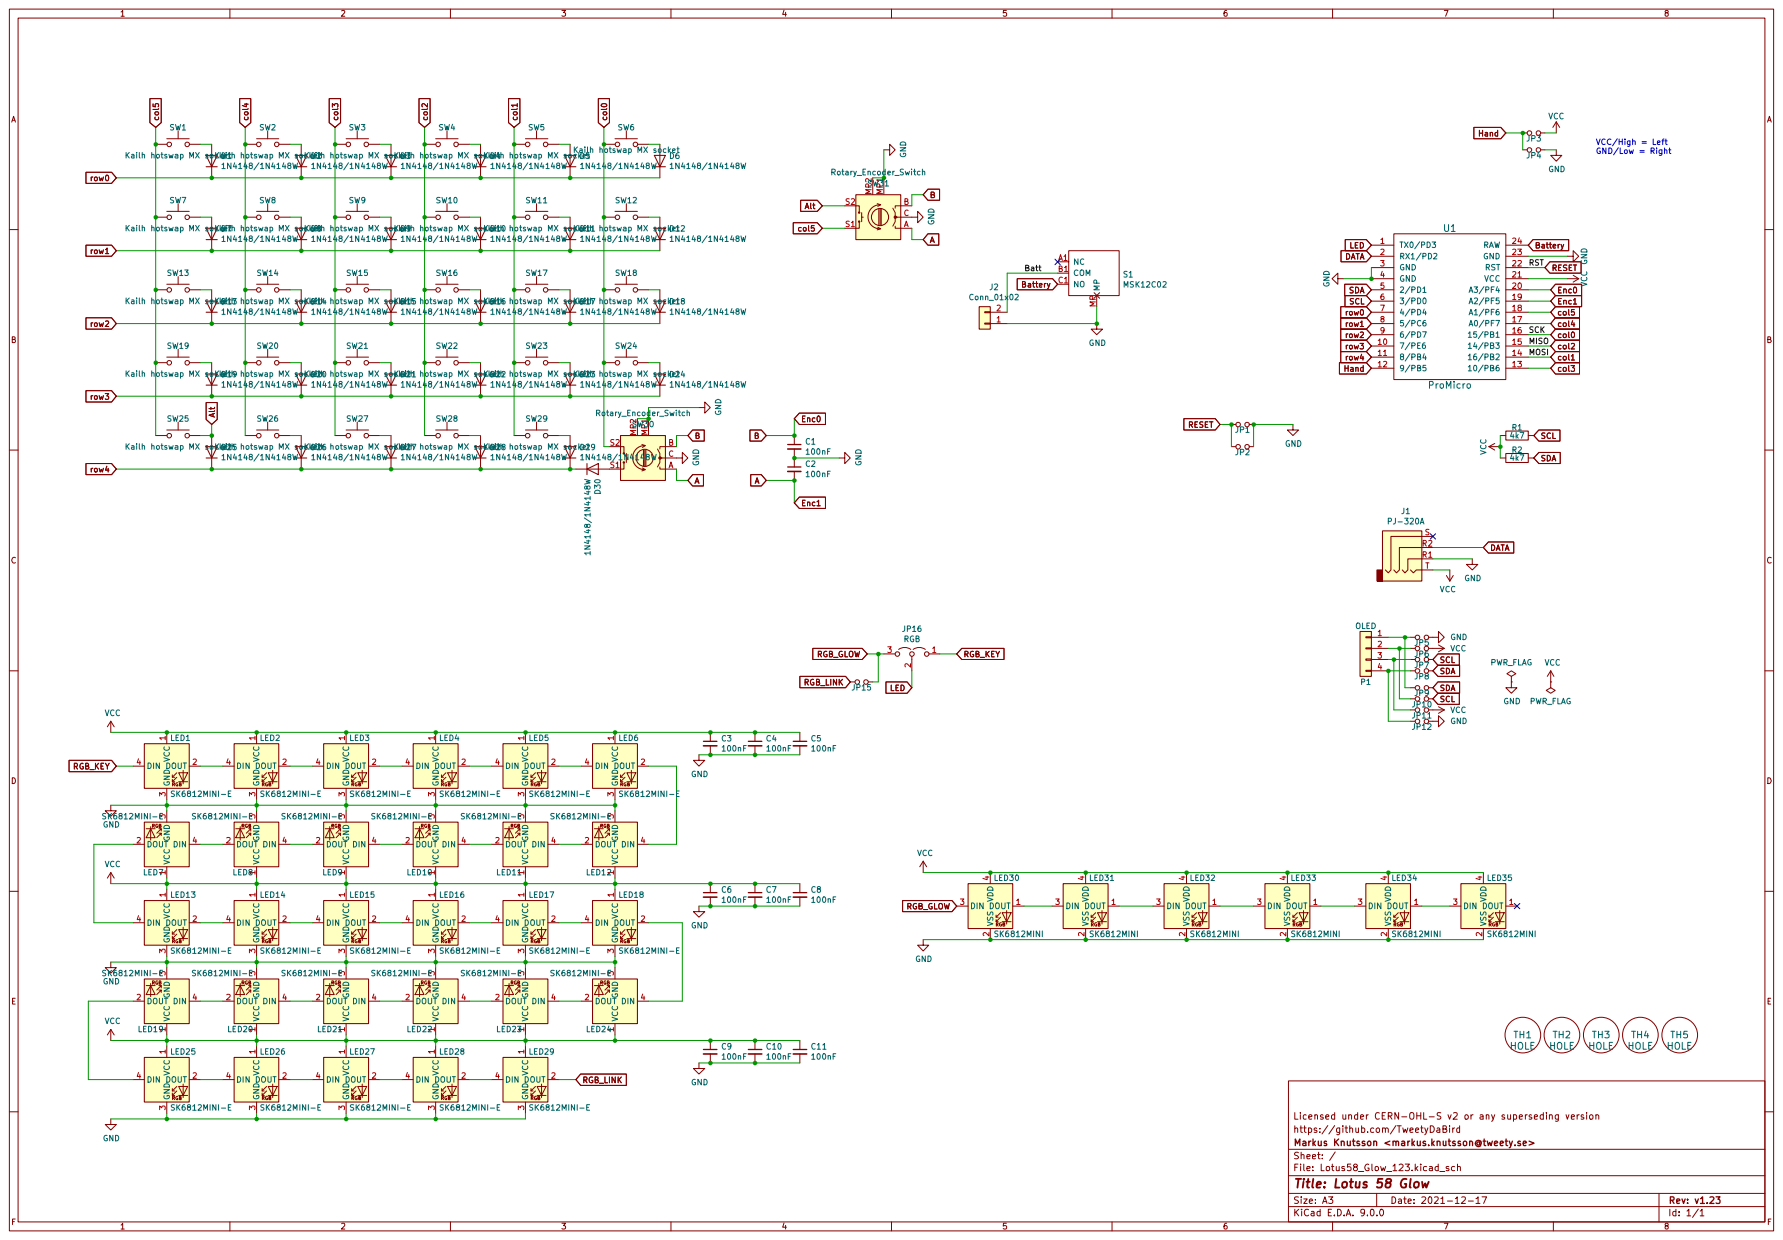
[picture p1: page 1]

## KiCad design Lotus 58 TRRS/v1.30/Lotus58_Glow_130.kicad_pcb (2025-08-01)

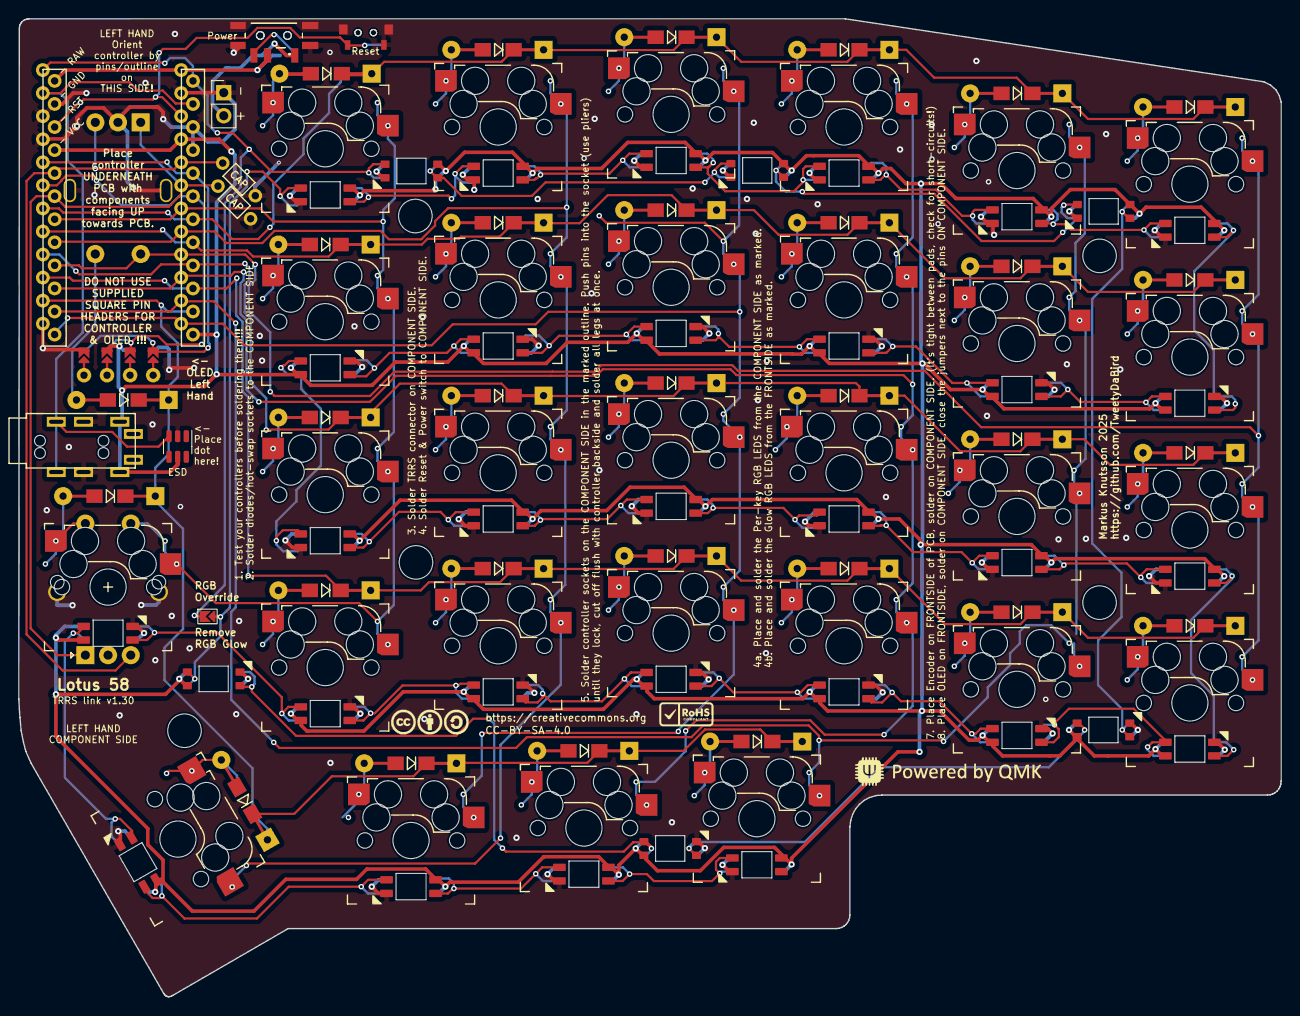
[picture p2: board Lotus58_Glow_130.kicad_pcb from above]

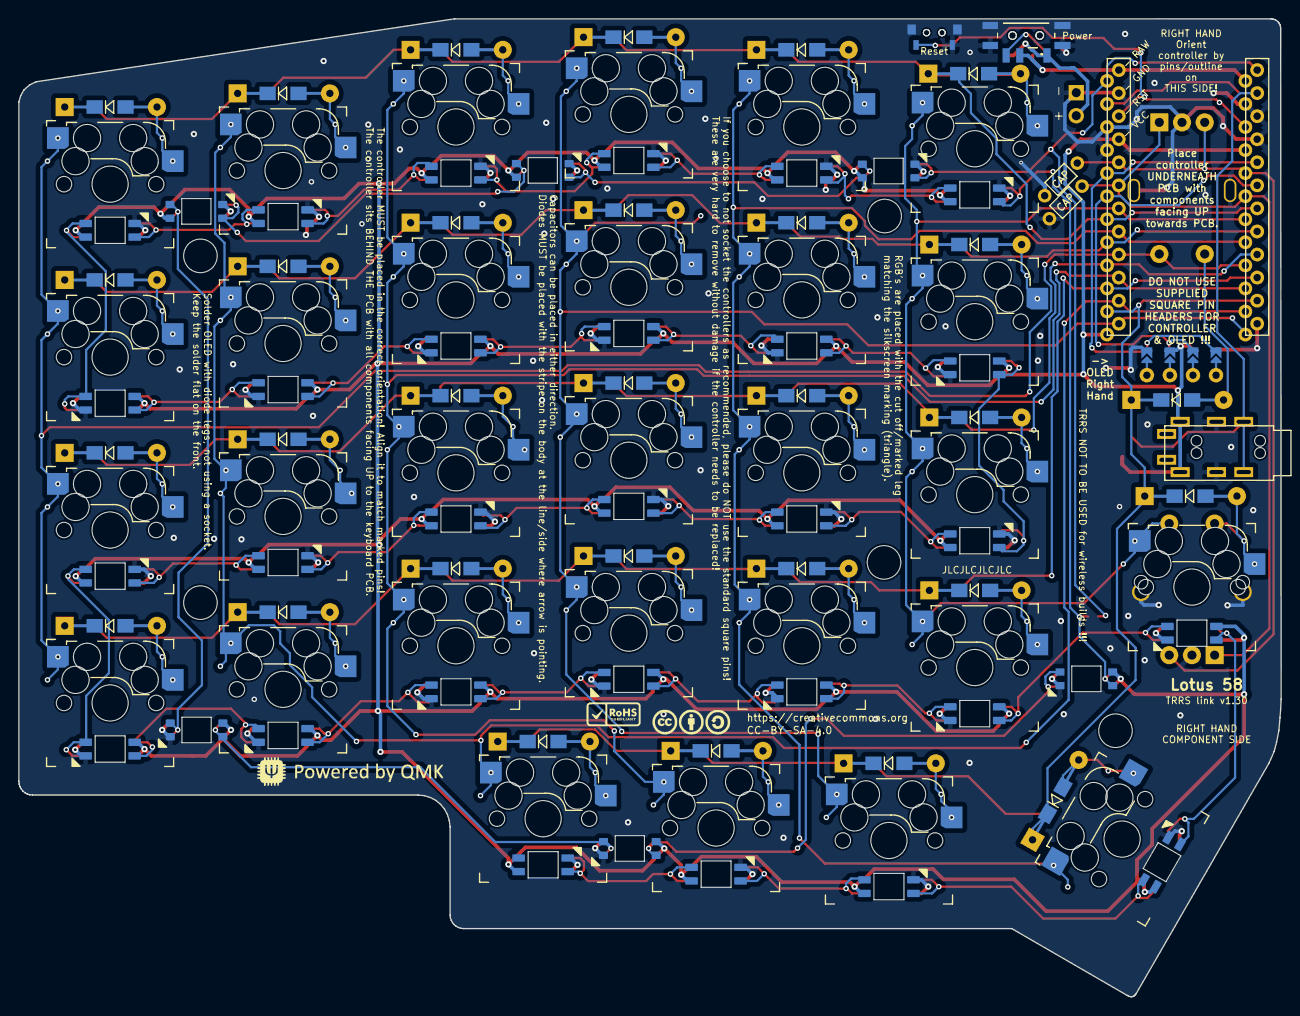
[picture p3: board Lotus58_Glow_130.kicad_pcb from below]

Board: 2 copper layers, 139.1 x 107.7 mm, 117 parts (70 on the bottom side), 86 nets.

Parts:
C1, C2: 50V/100nF axial; RESISTOR_Reversible
D1, D2, D3, D4, D5, D6, D7, D8, D9, D10, D11, D12, D13, D14, D15, D16, D17, D18, D19, D20, D21, D22, D23, D24, D25, D26, D27, D28, D29, D30: 1N4148/1N4148W; Diode_DO35_SOD123
J1: PJ-320A; MJ-4PP-9_alim
J2: Conn_01x02; PinHeader_1x02_P2.54mm_Vertical
JP5: FULL; Jumper_min_v2
LED1, LED2, LED3, LED4, LED5, LED6: SK6812MINI-E; MX_SK6812MINI-E_REVERSIBLE_special_v2
LED7, LED8, LED9, LED10, LED11, LED12, LED13, LED14, LED15, LED16, LED17, LED18, LED19, LED20, LED21, LED22, LED23, LED24, LED25, LED26, LED27, LED28, LED29, LED30, LED31, LED32, LED33, LED34, LED35: SK6803MINI-E; MX_SK6812MINI-E_REVERSIBLE
Logo1, Logo8: QMK_Logo; qmk logo
Logo2, Logo7: CC-BY-SA-4.0; CC_BY_SA_40_line
P1: OLED; SSD1306-0.91-OLED-4pin-128x32 doublesided
RES1, RES2: TS-A002; YTS-A002
S1, S2: MSK12C02
SW1, SW2, SW3, SW4, SW5, SW6, SW7, SW8, SW9, SW10, SW11, SW12, SW13, SW14, SW15, SW16, SW17, SW18, SW19, SW20, SW21, SW22, SW23, SW24, SW25, SW26, SW27, SW28, SW29: Kailh hotswap MX socket; SW_MX_HotSwap_Reversible
SW30: EC_11; RotaryEncoder_Alps_EC11E-Switch_Vertical_H20_special
SW31: EC_11; RotaryEncoder_Alps_EC11E-Switch_Special
TH1, TH2, TH3, TH4, TH5: HOLE; Spacer PCB hole
U1: Controller; ProMicro_Reversible_orig
U2: SRV05-4; SOT-23-6

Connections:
/Batt: J2.2, S1.NC, S2.NC
A: C2.2, SW30.A, SW31.A, U1.19 (A2/PF5)
Alt: D25.2 (A), SW25.2, SW31.S2
B: C1.2, SW30.B, SW31.B, U1.20 (A3/PF4)
Battery: S1.COM, S2.COM, U1.24 (RAW)
DATA: J1.R2, U1.2 (RX1/PD2), U2.3 (IO2)
GND: C1.1, C2.1, J1.R1, J2.1, LED1.3 (GND), LED2.3 (GND), LED3.3 (GND), LED4.3 (GND), LED5.3 (GND), LED6.3 (GND), LED7.3 (GND), LED8.3 (GND), LED9.3 (GND), LED10.3 (GND), LED11.3 (GND), LED12.3 (GND), LED13.3 (GND), LED14.3 (GND), LED15.3 (GND), LED16.3 (GND), LED17.3 (GND), LED18.3 (GND), LED19.3 (GND), LED20.3 (GND), LED21.3 (GND), LED22.3 (GND), LED23.3 (GND), LED24.3 (GND), LED25.3 (GND), LED26.3 (GND), LED27.3 (GND), LED28.3 (GND), LED29.3 (GND), LED30.3 (GND), LED31.3 (GND), LED32.3 (GND), LED33.3 (GND), LED34.3 (GND), LED35.3 (GND), P1.1 (GND), RES1.2, RES1.3, RES2.2, RES2.3, S1.MP (GND), S2.MP (GND), SW30.C, SW30.MP1 (GND), SW30.MP2 (GND), SW31.C, SW31.MP1 (GND), SW31.MP2 (GND), U1.3 (GND), U1.4 (GND), U1.23 (GND), U2.2 (VN)
LED: JP5.1, LED1.4 (DIN), U1.1 (TX0/PD3)
unnamed: D1.2 (A), SW1.2
unnamed: D2.2 (A), SW2.2
unnamed: D3.2 (A), SW3.2
unnamed: D4.2 (A), SW4.2
unnamed: D5.2 (A), SW5.2
unnamed: D6.2 (A), SW6.2
unnamed: D7.2 (A), SW7.2
unnamed: D8.2 (A), SW8.2
unnamed: D9.2 (A), SW9.2
unnamed: D10.2 (A), SW10.2
unnamed: D11.2 (A), SW11.2
unnamed: D12.2 (A), SW12.2
unnamed: D13.2 (A), SW13.2
unnamed: D14.2 (A), SW14.2
unnamed: D15.2 (A), SW15.2
unnamed: D16.2 (A), SW16.2
unnamed: D17.2 (A), SW17.2
unnamed: D18.2 (A), SW18.2
unnamed: D19.2 (A), SW19.2
unnamed: D20.2 (A), SW20.2
unnamed: D21.2 (A), SW21.2
unnamed: D22.2 (A), SW22.2
unnamed: D23.2 (A), SW23.2
unnamed: D24.2 (A), SW24.2
unnamed: D26.2 (A), SW26.2
unnamed: D27.2 (A), SW27.2
unnamed: D28.2 (A), SW28.2
unnamed: D29.2 (A), SW29.2
unnamed: D30.2 (A), SW30.S1
unnamed: LED1.2 (DOUT), LED2.4 (DIN)
unnamed: LED2.2 (DOUT), LED3.4 (DIN)
unnamed: LED3.2 (DOUT), LED4.4 (DIN)
unnamed: LED4.2 (DOUT), LED5.4 (DIN)
unnamed: LED5.2 (DOUT), LED6.4 (DIN)
unnamed: LED7.2 (DOUT), LED8.4 (DIN)
unnamed: LED8.2 (DOUT), LED9.4 (DIN)
unnamed: LED9.2 (DOUT), LED10.4 (DIN)
unnamed: LED10.2 (DOUT), LED11.4 (DIN)
unnamed: LED11.2 (DOUT), LED12.4 (DIN)
unnamed: LED12.2 (DOUT), LED18.4 (DIN)
unnamed: LED13.4 (DIN), LED14.2 (DOUT)
unnamed: LED13.2 (DOUT), LED19.4 (DIN)
unnamed: LED14.4 (DIN), LED15.2 (DOUT)
unnamed: LED15.4 (DIN), LED16.2 (DOUT)
unnamed: LED16.4 (DIN), LED17.2 (DOUT)
unnamed: LED17.4 (DIN), LED18.2 (DOUT)
unnamed: LED19.2 (DOUT), LED20.4 (DIN)
unnamed: LED20.2 (DOUT), LED21.4 (DIN)
unnamed: LED21.2 (DOUT), LED22.4 (DIN)
unnamed: LED22.2 (DOUT), LED23.4 (DIN)
unnamed: LED23.2 (DOUT), LED24.4 (DIN)
unnamed: LED24.2 (DOUT), LED30.4 (DIN)
unnamed: LED25.4 (DIN), LED26.2 (DOUT)
unnamed: LED25.2 (DOUT), LED31.4 (DIN)
unnamed: LED26.4 (DIN), LED27.2 (DOUT)
unnamed: LED27.4 (DIN), LED28.2 (DOUT)
unnamed: LED28.4 (DIN), LED29.2 (DOUT)
unnamed: LED29.4 (DIN), LED30.2 (DOUT)
unnamed: LED31.2 (DOUT), LED32.4 (DIN)
unnamed: LED32.2 (DOUT), LED33.4 (DIN)
unnamed: LED33.2 (DOUT), LED34.4 (DIN)
unnamed: LED34.2 (DOUT), LED35.4 (DIN)
RESET: RES1.1, RES2.1, U1.22 (RST)
RGB_LINK: JP5.2, LED6.2 (DOUT), LED7.4 (DIN)
SCL: P1.3 (SCL), U1.6 (3/PD0)
SDA: P1.4 (SDA), U1.5 (2/PD1)
VCC: J1.T, LED1.1 (VCC), LED2.1 (VCC), LED3.1 (VCC), LED4.1 (VCC), LED5.1 (VCC), LED6.1 (VCC), LED7.1 (VCC), LED8.1 (VCC), LED9.1 (VCC), LED10.1 (VCC), LED11.1 (VCC), LED12.1 (VCC), LED13.1 (VCC), LED14.1 (VCC), LED15.1 (VCC), LED16.1 (VCC), LED17.1 (VCC), LED18.1 (VCC), LED19.1 (VCC), LED20.1 (VCC), LED21.1 (VCC), LED22.1 (VCC), LED23.1 (VCC), LED24.1 (VCC), LED25.1 (VCC), LED26.1 (VCC), LED27.1 (VCC), LED28.1 (VCC), LED29.1 (VCC), LED30.1 (VCC), LED31.1 (VCC), LED32.1 (VCC), LED33.1 (VCC), LED34.1 (VCC), LED35.1 (VCC), P1.2 (VCC), U1.21 (VCC), U2.5 (VP)
col0: SW6.1, SW12.1, SW18.1, SW24.1, SW30.S2, U1.16 (15/PB1)
col1: SW5.1, SW11.1, SW17.1, SW23.1, SW29.1, U1.14 (16/PB2)
col2: SW4.1, SW10.1, SW16.1, SW22.1, SW28.1, U1.15 (14/PB3)
col3: SW3.1, SW9.1, SW15.1, SW21.1, SW27.1, U1.13 (10/PB6)
col4: SW2.1, SW8.1, SW14.1, SW20.1, SW26.1, U1.17 (A0/PF7)
col5: SW1.1, SW7.1, SW13.1, SW19.1, SW25.1, SW31.S1, U1.18 (A1/PF6)
row0: D1.1 (K), D2.1 (K), D3.1 (K), D4.1 (K), D5.1 (K), D6.1 (K), U1.7 (4/PD4)
row1: D7.1 (K), D8.1 (K), D9.1 (K), D10.1 (K), D11.1 (K), D12.1 (K), U1.8 (5/PC6)
row2: D13.1 (K), D14.1 (K), D15.1 (K), D16.1 (K), D17.1 (K), D18.1 (K), U1.9 (6/PD7)
row3: D19.1 (K), D20.1 (K), D21.1 (K), D22.1 (K), D23.1 (K), D24.1 (K), U1.10 (7/PE6)
row4: D25.1 (K), D26.1 (K), D27.1 (K), D28.1 (K), D29.1 (K), D30.1 (K), U1.11 (8/PB4)

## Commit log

2025-07-09 v1.23 file cleanup
    Added pdf
    [Lotus58_Glow_125.kicad_pcb]
2025-08-01 TRRS v1.30
    [Lotus58_Glow_130.kicad_pcb]

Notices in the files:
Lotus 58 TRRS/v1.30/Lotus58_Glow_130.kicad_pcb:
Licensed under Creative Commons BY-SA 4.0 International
